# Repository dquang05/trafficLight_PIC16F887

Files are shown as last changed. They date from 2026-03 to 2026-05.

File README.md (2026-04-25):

# Traffic Light Controller with PIC16F887

<p align="center">
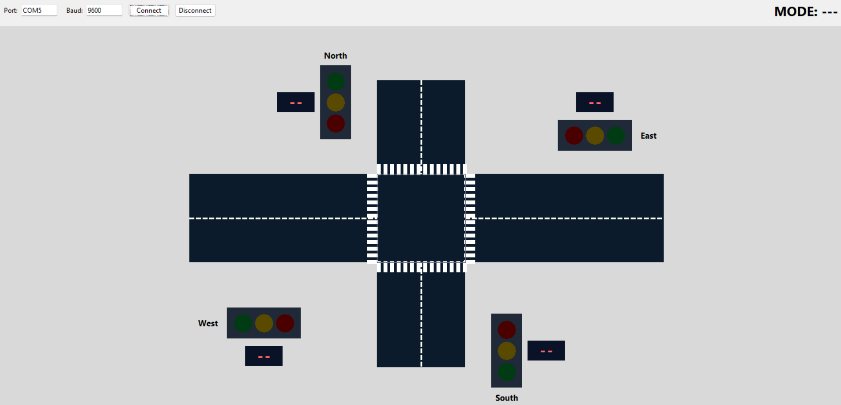
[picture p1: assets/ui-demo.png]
UI Demo
  
</p>

A embedded systems project that implements a 2-road traffic light controller on **PIC16F887**, with a **Python Tkinter desktop UI** for monitoring and control over UART. The project focuses on firmware development, peripheral integration, timer-based state control, and PC-side visualization.

## Features

- PIC16F887-based traffic light controller firmware
- 3 operating modes: **AUTO**, **MANUAL**, and **FLASHING**
- UART-based communication between the microcontroller and desktop UI
- Python Tkinter interface for live traffic light visualization
- I2C LCD for mode display on the hardware side
- Button control and serial command control support

## Operating Modes

### AUTO
Runs the normal traffic cycle automatically using timer-based state transitions. The UI displays countdown values for both roads.

### MANUAL
Allows the user to manually select which road gets the green light from the desktop UI.

### FLASHING
Puts the system into a caution mode where the yellow lights blink.

## How It Works

The PIC firmware handles the traffic light state machine, button input, UART command processing, and LCD updates. A timer interrupt is used for timekeeping, while the main loop updates the current mode and periodically sends system state data to the PC.

The desktop UI connects through a serial port, sends commands, and visualizes the current traffic light states in real time.

## Controls

Supported serial/UI commands:

- `A` → AUTO
- `N` → MANUAL
- `F` → FLASHING
- `M` → NEXT MODE
- `R1` → Road 1 Go
- `R2` → Road 2 Go

## How to Use

1. Build and flash the firmware to the PIC16F887.
2. Connect the board to the PC through UART.
3. Run the Python UI.
4. Select the correct COM port and baud rate, then press **Connect**.
5. Use the UI buttons to switch modes and control the intersection.

## Wiring Notes

- `RC3` → I2C SCL
- `RC4` → I2C SDA
- `RB0`, `RB1`, `RB2` → push buttons
- UART baud rate in the current setup: **9600**

## Fault notes
- This is a small project, i do not optimal it for fault tolerance, so there are some faults in the code, such as:
  - All the components must be connected or the hardware may not function correctly.
  - If the LCD is not properly initialized or connected, it will not run correctly until the MCU is reset.

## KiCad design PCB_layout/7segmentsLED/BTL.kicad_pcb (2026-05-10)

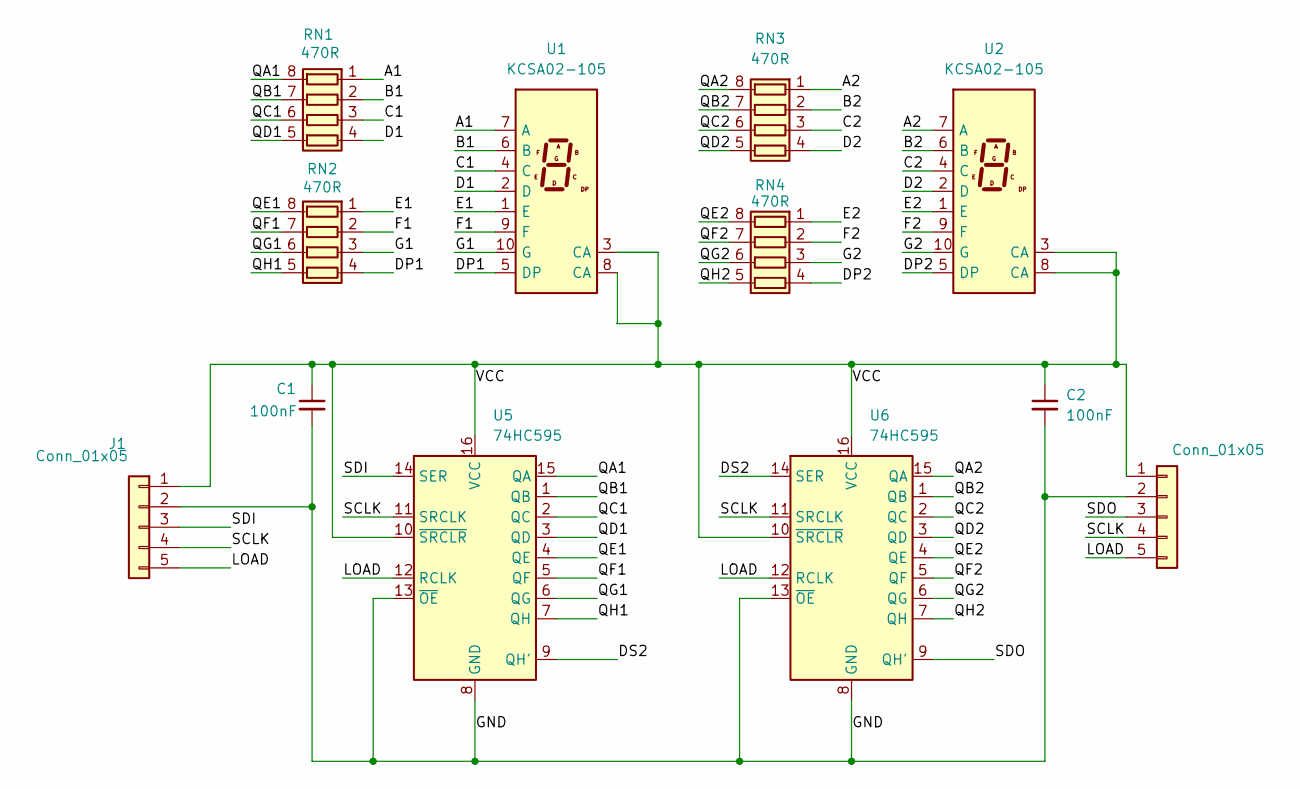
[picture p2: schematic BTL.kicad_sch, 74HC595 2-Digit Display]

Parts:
C1, C2: 100nF; C_0805_2012Metric
J1, J2: Conn_01x05; PinHeader_1x05_P2.54mm_Vertical
RN1, RN2, RN3, RN4: 470R; R_Array_Convex_4x0603
U1, U2: KCSA02-105; D1X8K
U5, U6: 74HC595; SOIC-16_3.9x9.9mm_P1.27mm

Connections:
/A1: RN1.1 (R1.1), U1.7 (A)
/A2: RN3.1 (R1.1), U2.7 (A)
/B1: RN1.2 (R2.1), U1.6 (B)
/B2: RN3.2 (R2.1), U2.6 (B)
/C1: RN1.3 (R3.1), U1.4 (C)
/C2: RN3.3 (R3.1), U2.4 (C)
/D1: RN1.4 (R4.1), U1.2 (D)
/D2: RN3.4 (R4.1), U2.2 (D)
/DP1: RN2.4 (R4.1), U1.5 (DP)
/DP2: RN4.4 (R4.1), U2.5 (DP)
/DS2: U5.9 (QH'), U6.14 (SER)
/E1: RN2.1 (R1.1), U1.1 (E)
/E2: RN4.1 (R1.1), U2.1 (E)
/F1: RN2.2 (R2.1), U1.9 (F)
/F2: RN4.2 (R2.1), U2.9 (F)
/G1: RN2.3 (R3.1), U1.10 (G)
/G2: RN4.3 (R3.1), U2.10 (G)
/GND: C1.2, C2.2, J1.2, J2.2, U5.8 (GND), U5.13 (~OE), U6.8 (GND), U6.13 (~OE)
/LOAD: J1.5, J2.5, U5.12 (RCLK), U6.12 (RCLK)
/QA1: RN1.8 (R1.2), U5.15 (QA)
/QA2: RN3.8 (R1.2), U6.15 (QA)
/QB1: RN1.7 (R2.2), U5.1 (QB)
/QB2: RN3.7 (R2.2), U6.1 (QB)
/QC1: RN1.6 (R3.2), U5.2 (QC)
/QC2: RN3.6 (R3.2), U6.2 (QC)
/QD1: RN1.5 (R4.2), U5.3 (QD)
/QD2: RN3.5 (R4.2), U6.3 (QD)
/QE1: RN2.8 (R1.2), U5.4 (QE)
/QE2: RN4.8 (R1.2), U6.4 (QE)
/QF1: RN2.7 (R2.2), U5.5 (QF)
/QF2: RN4.7 (R2.2), U6.5 (QF)
/QG1: RN2.6 (R3.2), U5.6 (QG)
/QG2: RN4.6 (R3.2), U6.6 (QG)
/QH1: RN2.5 (R4.2), U5.7 (QH)
/QH2: RN4.5 (R4.2), U6.7 (QH)
/SCLK: J1.4, J2.4, U5.11 (SRCLK), U6.11 (SRCLK)
/SDI: J1.3, U5.14 (SER)
/SDO: J2.3, U6.9 (QH')
/VCC: C1.1, C2.1, J1.1, J2.1, U1.3 (CA), U1.8 (CA), U2.3 (CA), U2.8 (CA), U5.10 (~SRCLR), U5.16 (VCC), U6.10 (~SRCLR), U6.16 (VCC)

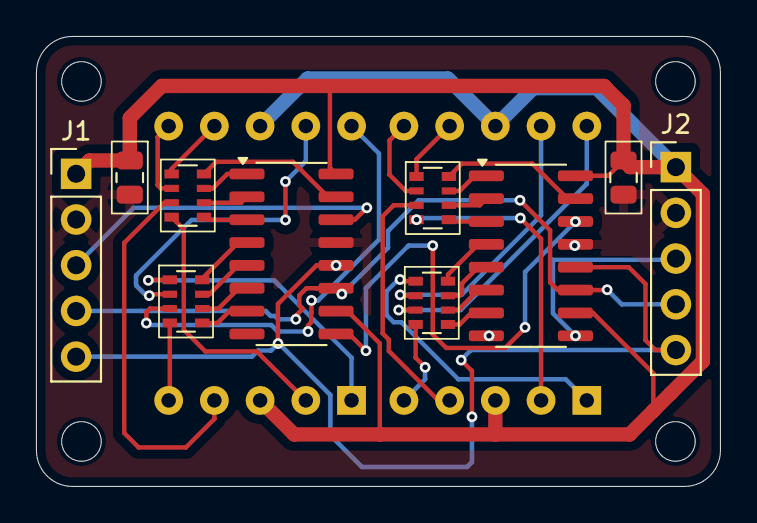
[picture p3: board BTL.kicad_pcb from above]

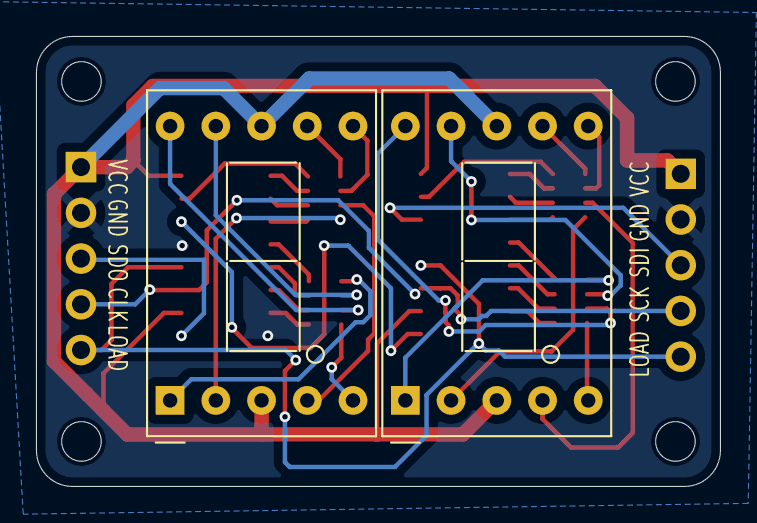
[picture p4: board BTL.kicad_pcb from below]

Board: 2 copper layers, 38.0 x 25.0 mm, 12 parts (2 on the bottom side), 39 nets.

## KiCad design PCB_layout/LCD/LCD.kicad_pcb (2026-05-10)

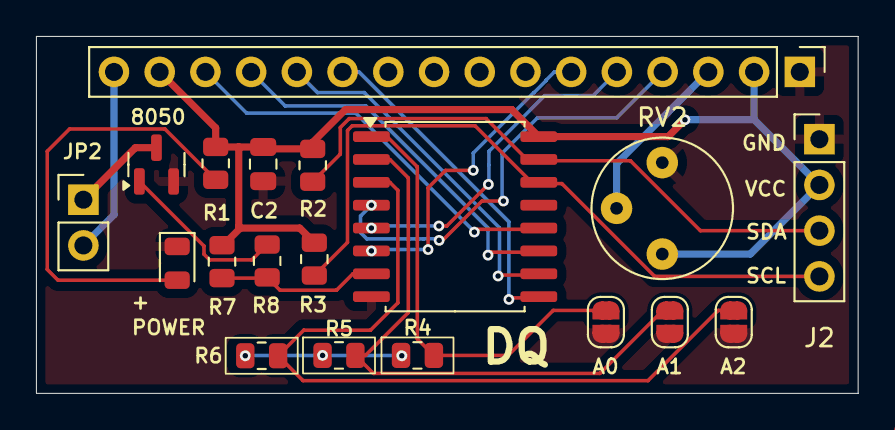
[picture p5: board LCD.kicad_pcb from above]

Board: 2 copper layers, 45.6 x 19.8 mm, 19 parts (0 on the bottom side), 20 nets.

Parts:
8050: SS8050; SOT-23
A0, A1, A2: SolderJumper_2_Open; SolderJumper-2_P1.3mm_Open_RoundedPad1.0x1.5mm
C2: C; C_0805_2012Metric
J1: Conn_01x16; PinHeader_1x16_P2.54mm_Vertical
J2: Conn_01x04; PinHeader_1x04_P2.54mm_Vertical
JP2: Jumper_2_Bridged; PinHeader_1x02_P2.54mm_Vertical
POWER: LED; LED_0805_2012Metric
R1: 1k; R_0805_2012Metric
R1#2, R2, R2#2, R3, R3#2, R7, R8: 4k7; R_0805_2012Metric
RV2: 10k; Potentiometer_Bourns_3339P_Vertical_HandSoldering
U1: PCF8574T; SOIC-16W_7.5x10.3mm_P1.27mm

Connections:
BL: R7.2, R8.2, U1.7 (P3)
D4: J1.11, U1.9 (P4)
D5: J1.12, U1.10 (P5)
D6: J1.13, U1.11 (P6)
D7: J1.14, U1.12 (P7)
EN: J1.6, U1.6 (P2)
GND: 8050.2 (E), A0.2 (B), A1.2 (B), A2.2 (B), C2.2, J1.1, J2.1, POWER.1 (K), RV2.3, U1.8 (GND)
K: J1.16, JP2.2 (B)
unnamed: POWER.2 (A), R1.2
unnamed: 8050.3 (C), JP2.1 (A)
unnamed: A2.1 (A), R1#2.2, U1.3 (A2)
unnamed: A1.1 (A), R2.2, U1.2 (A1)
unnamed: A0.1 (A), R3.2, U1.1 (A0)
unnamed: 8050.1 (B), R8.1
RS: J1.4, U1.4 (P0)
RW: J1.5, U1.5 (P1)
SCL: J2.4, R3#2.2, U1.14 (SCL)
SDA: J2.3, R2#2.2, U1.15 (SDA)
V0: J1.3, RV2.2
VDD: C2.1, J1.2, J1.15, J2.2, R1.1, R1#2.1, R2.1, R2#2.1, R3.1, R3#2.1, R7.1, RV2.1, U1.16 (VDD)

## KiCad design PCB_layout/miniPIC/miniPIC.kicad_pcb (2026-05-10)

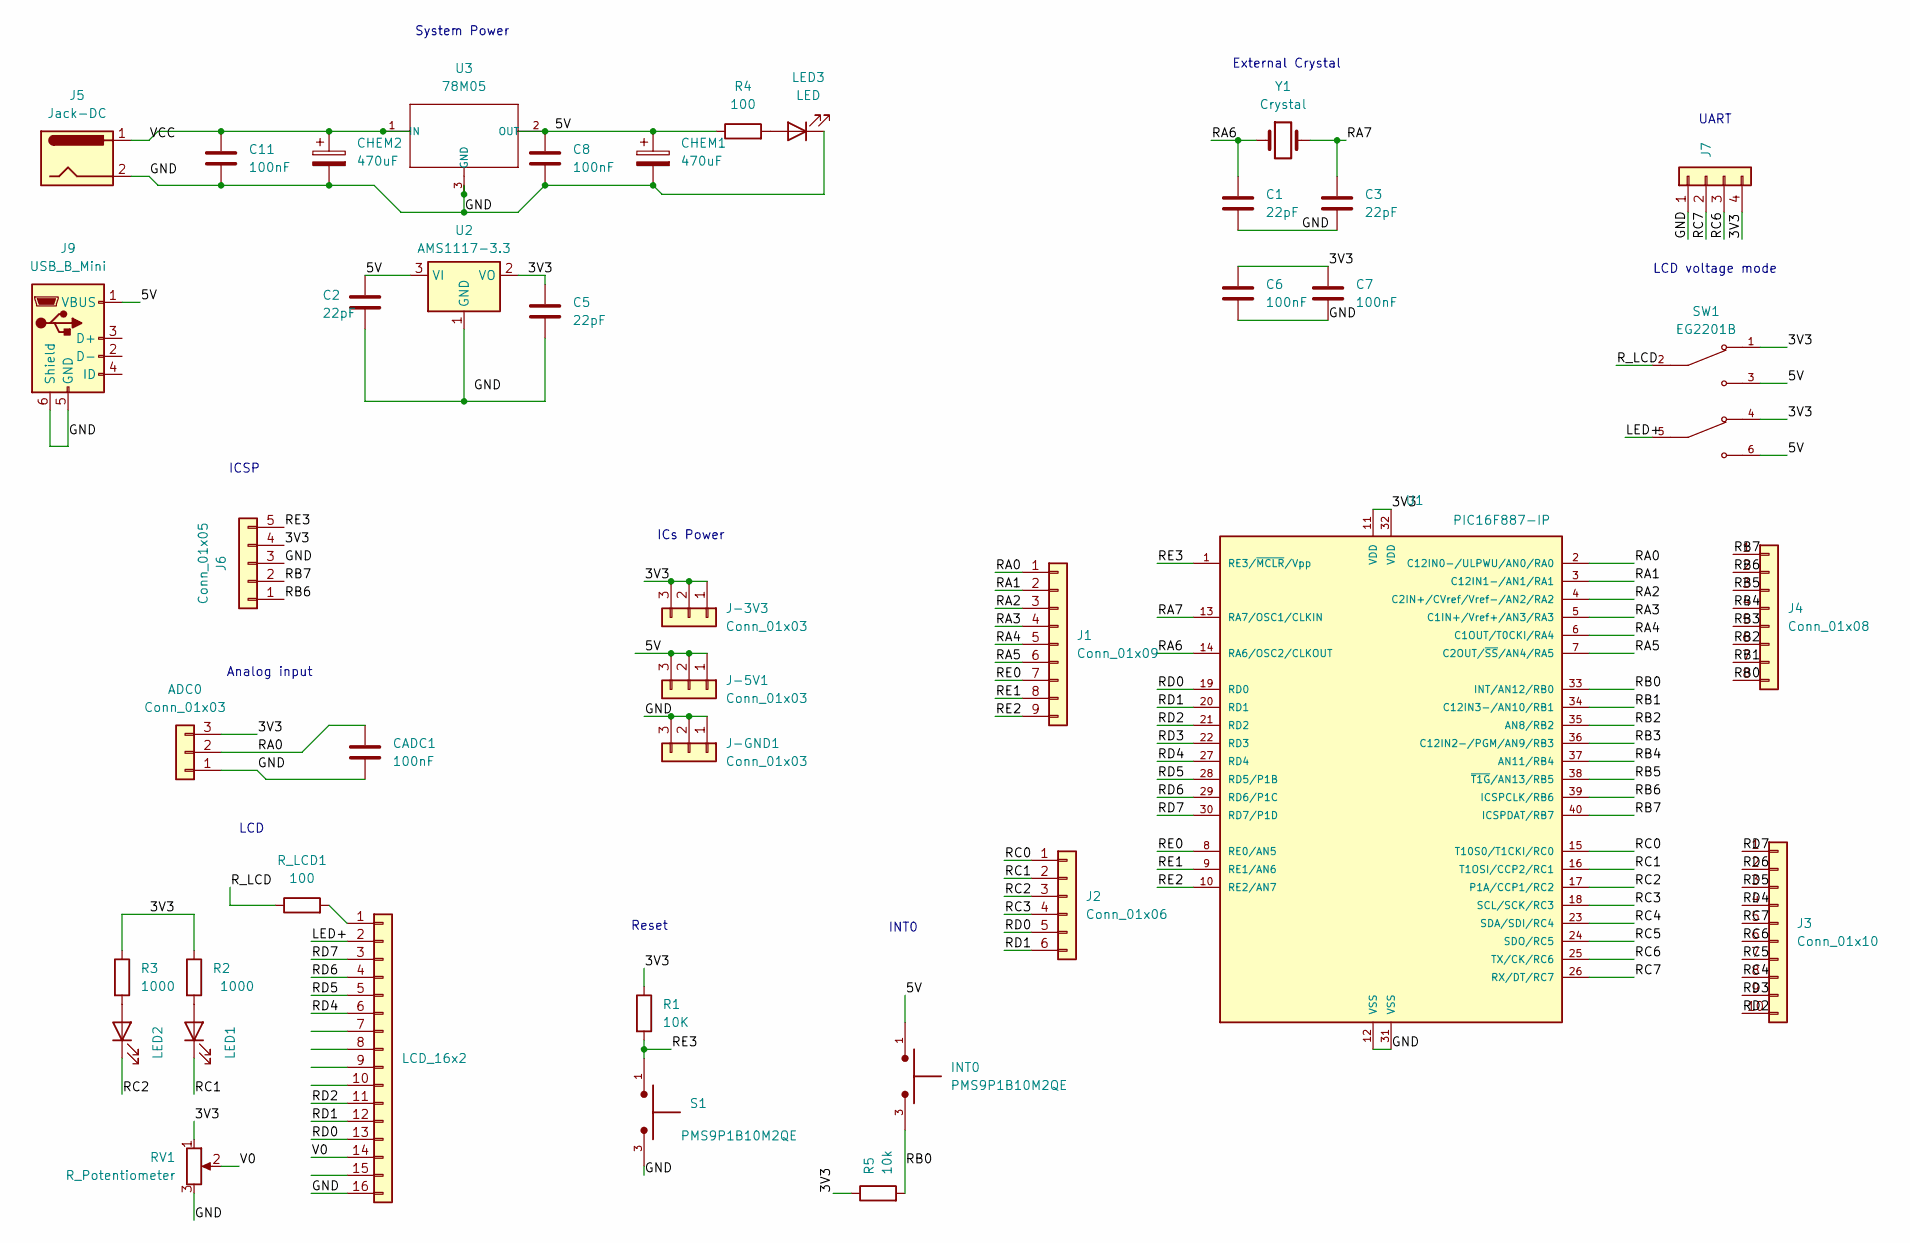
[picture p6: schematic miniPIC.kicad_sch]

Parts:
ADC0: Conn_01x03; PinHeader_1x03_P2.54mm_Vertical
C1, C2, C3, C5: 22pF; CP_EIA-1608-08_AVX-J
C6, C7, C8, C11: 100nF; CP_EIA-1608-08_AVX-J
CADC1: 100nF; CP_EIA-1608-08_AVX-J
CHEM1, CHEM2: 470uF; CP_Radial_D7.5mm_P2.50mm
INT0: PMS9P1B10M2QE; SW_PMS9P1B10M2QE; PARTREV A1
J1: Conn_01x09; PinHeader_1x09_P2.54mm_Vertical
J2: Conn_01x06; PinHeader_1x06_P2.54mm_Vertical
J3: Conn_01x10; PinHeader_1x10_P2.54mm_Vertical
J4: Conn_01x08; PinHeader_1x08_P2.54mm_Vertical
J5: Jack-DC; BarrelJack_Horizontal
J6: Conn_01x05; PinHeader_1x05_P2.54mm_Vertical
J7: Conn_01x04; PinSocket_1x04_P2.54mm_Vertical
J9: USB_B_Mini; USB_Mini-B_Lumberg_2486_01_Horizontal
J-3V3, J-5V1: Conn_01x03; PinHeader_1x03_P2.54mm_Vertical
J-GND1: Conn_01x03; PinHeader_1x03_P2.54mm_Vertical
LCD_16x2: Conn_01x16; PinSocket_1x16_P2.54mm_Vertical
LED1, LED2: LED; LED_0603_1608Metric_Pad1.05x0.95mm_HandSolder
LED3: LED; LED_1206_3216Metric_Pad1.42x1.75mm_HandSolder
R1: 10K; R_0805_2012Metric_Pad1.20x1.40mm_HandSolder
R2, R3: 1000; R_0805_2012Metric_Pad1.20x1.40mm_HandSolder
R4: 100; R_0805_2012Metric_Pad1.20x1.40mm_HandSolder
R5: 10k; R_0805_2012Metric_Pad1.20x1.40mm_HandSolder
RV1: R_Potentiometer; Potentiometer_Bourns_3266W_Vertical
R_LCD1: 100; R_0805_2012Metric_Pad1.20x1.40mm_HandSolder
S1: PMS9P1B10M2QE; SW_PMS9P1B10M2QE; PARTREV A1
SW1: EG2201B; SW_EG2201B; PARTREV C
U1: PIC16F887-IP; DIP1543W47P254L5175H635Q40
U2: AMS1117-3.3; SOT-223-3_TabPin2
U3: 78M05; TO-252-2
Y1: Crystal; Crystal_HC49-4H_Vertical

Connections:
/3V3: ADC0.3, C5.1, C6.1, C7.1, J6.4, J7.4, J-3V3.1, J-3V3.2, J-3V3.3, R1.1, R2.1, R3.1, R5.1, RV1.1, SW1.1, SW1.4, U1.11 (VDD), U1.32 (VDD), U2.2 (VO)
/5V: C2.1, C8.1, CHEM1.1, INT0.1, J9.1 (VBUS), J-5V1.1, J-5V1.2, J-5V1.3, R4.1, SW1.3, SW1.6, U2.3 (VI), U3.2 (OUT)
/LED+: LCD_16x2.2, SW1.5
/RA0: ADC0.2, CADC1.1, J1.1, U1.2 (C12IN0-/ULPWU/AN0/RA0)
/RA1: J1.2, U1.3 (C12IN1-/AN1/RA1)
/RA2: J1.3, U1.4 (C2IN+/CVref/Vref-/AN2/RA2)
/RA3: J1.4, U1.5 (C1IN+/Vref+/AN3/RA3)
/RA4: J1.5, U1.6 (C1OUT/T0CKI/RA4)
/RA5: J1.6, U1.7 (C2OUT/~SS/AN4/RA5)
/RA6: C1.1, U1.14 (RA6/OSC2/CLKOUT), Y1.1
/RA7: C3.1, U1.13 (RA7/OSC1/CLKIN), Y1.2
/RB0: INT0.3, J4.8, R5.2, U1.33 (INT/AN12/RB0)
/RB1: J4.7, U1.34 (C12IN3-/AN10/RB1)
/RB2: J4.6, U1.35 (AN8/RB2)
/RB3: J4.5, U1.36 (C12IN2-/PGM/AN9/RB3)
/RB4: J4.4, U1.37 (AN11/RB4)
/RB5: J4.3, U1.38 (~T1G/AN13/RB5)
/RB6: J4.2, J6.1, U1.39 (ICSPCLK/RB6)
/RB7: J4.1, J6.2, U1.40 (ICSPDAT/RB7)
/RC0: J2.1, U1.15 (T10S0/T1CKI/RC0)
/RC1: J2.2, LED1.1 (K), U1.16 (T1OSI/CCP2/RC1)
/RC2: J2.3, LED2.1 (K), U1.17 (P1A/CCP1/RC2)
/RC3: J2.4, U1.18 (SCL/SCK/RC3)
/RC4: J3.8, U1.23 (SDA/SDI/RC4)
/RC5: J3.7, U1.24 (SDO/RC5)
/RC6: J3.6, J7.3, U1.25 (TX/CK/RC6)
/RC7: J3.5, J7.2, U1.26 (RX/DT/RC7)
/RD0: J2.5, LCD_16x2.13, U1.19 (RD0)
/RD1: J2.6, LCD_16x2.12, U1.20 (RD1)
/RD2: J3.10, LCD_16x2.11, U1.21 (RD2)
/RD3: J3.9, U1.22 (RD3)
/RD4: J3.4, LCD_16x2.6, U1.27 (RD4)
/RD5: J3.3, LCD_16x2.5, U1.28 (RD5/P1B)
/RD6: J3.2, LCD_16x2.4, U1.29 (RD6/P1C)
/RD7: J3.1, LCD_16x2.3, U1.30 (RD7/P1D)
/RE0: J1.7, U1.8 (RE0/AN5)
/RE1: J1.8, U1.9 (RE1/AN6)
/RE2: J1.9, U1.10 (RE2/AN7)
/RE3: J6.5, R1.2, S1.1, U1.1 (RE3/~MCLR/Vpp)
/R_LCD: R_LCD1.1, SW1.2
/V0: LCD_16x2.14, RV1.2
/VCC: C11.1, CHEM2.1, J5.1, U3.1 (IN)
unnamed: LCD_16x2.1, R_LCD1.2
unnamed: LED1.2 (A), R2.2
unnamed: LED2.2 (A), R3.2
unnamed: LED3.2 (A), R4.2

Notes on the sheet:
External Crystal
LCD
Reset
UART
System Power
INT0
LCD voltage mode
ICSP
ICs Power
Analog input

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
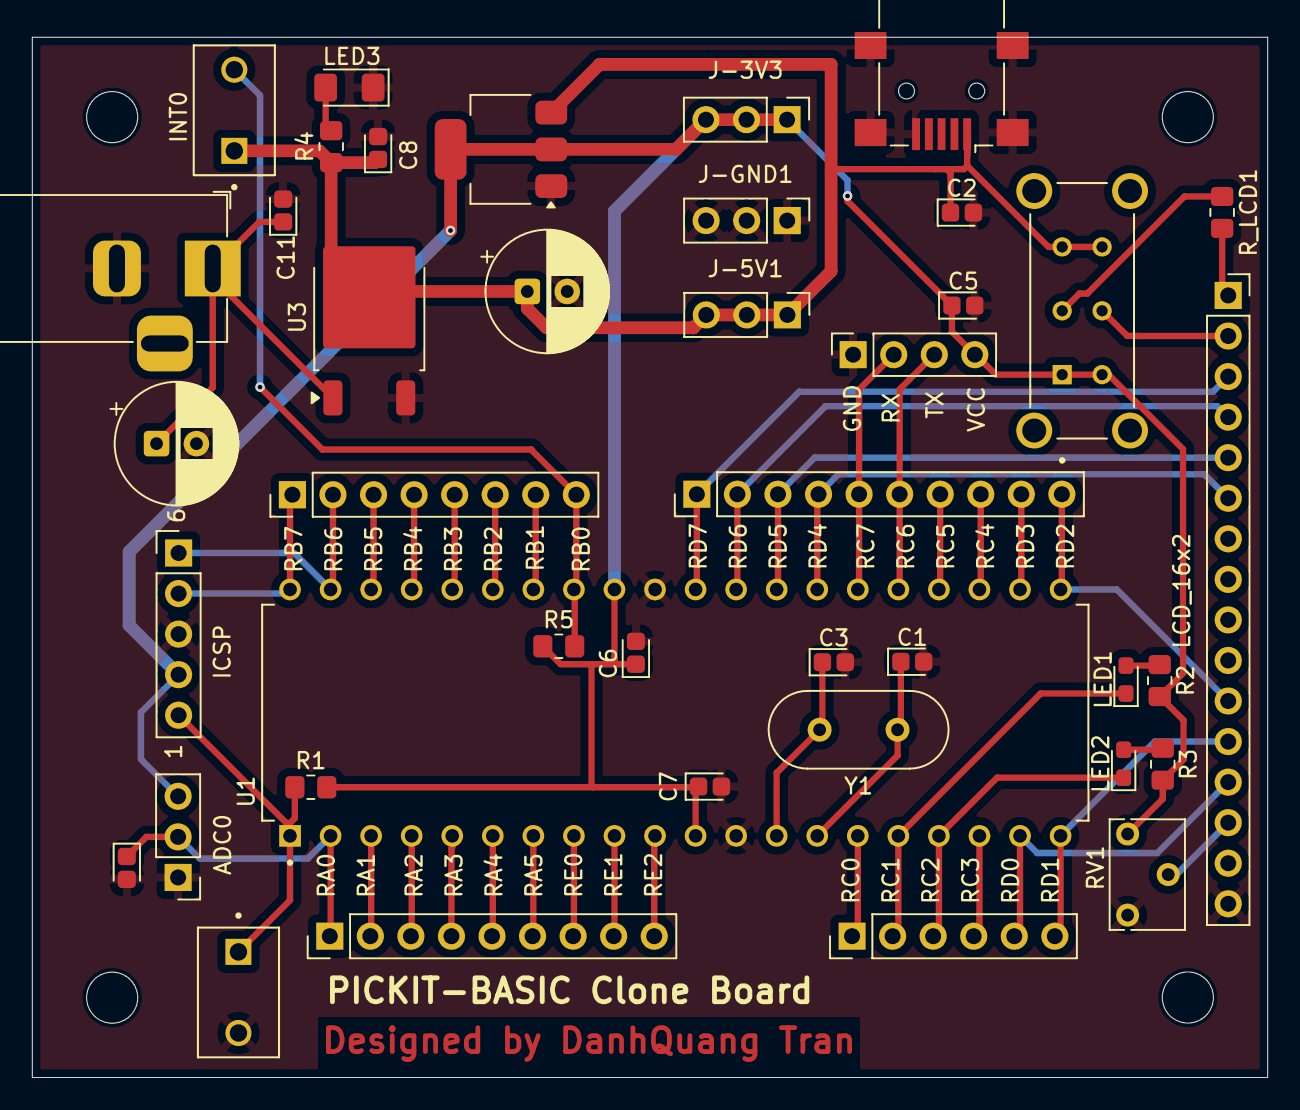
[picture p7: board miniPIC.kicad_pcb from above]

Board: 2 copper layers, 77.4 x 65.2 mm, 41 parts (0 on the bottom side), 47 nets.

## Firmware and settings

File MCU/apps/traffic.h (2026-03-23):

#ifndef TRAFFIC_H
#define TRAFFIC_H

#include <stdint.h>
#include <xc.h> 

// Các thông số thời gian
#define GREEN1_TIME   15
#define GREEN2_TIME   15
#define YELLOW_TIME  3

// Định nghĩa chân đèn giao thông
#define GREEN1   RA0  
#define YELLOW1  RA1  
#define RED1     RA2         
#define GREEN2   RA3  
#define YELLOW2  RA4    
#define RED2     RA5     

// Các biến toàn cục
extern volatile uint16_t timer_counter;
extern volatile uint8_t system_state;
extern volatile uint8_t exitsign;
extern volatile uint8_t mode;
extern volatile uint8_t countdown_NS; 
extern volatile uint8_t countdown_EW; 
extern volatile uint8_t road1_flag;
extern volatile uint8_t road2_flag;

// Các hàm điều khiển đèn
void Auto_Mode_Timer(void);
void Midnight_Mode_Timer(void);
void Manual_Mode(void);
void Opposite_State(void);
void Display_Countdown(uint8_t countdown_EW, uint8_t countdown_NS);
void ShiftOut_1Byte(uint8_t data);
void Clear_Display(void);

#endif

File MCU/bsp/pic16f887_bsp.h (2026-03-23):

#include <xc.h> // include processor files - each processor file is guarded.  

// CONFIG1
#pragma config FOSC = INTRC_NOCLKOUT        // Oscillator Selection bits (RC oscillator: CLKOUT function on RA6/OSC2/CLKOUT pin, RC on RA7/OSC1/CLKIN)
#pragma config WDTE = OFF       // Watchdog Timer Enable bit (WDT disabled and can be enabled by SWDTEN bit of the WDTCON register)

#pragma config CP = OFF         // Code Protection bit (Program memory code protection is disabled)
#pragma config CPD = OFF        // Data Code Protection bit (Data memory code protection is disabled)
#pragma config BOREN = ON       // Brown Out Reset Selection bits (BOR enabled)
#pragma config IESO = OFF       // Internal External Switchover bit (Internal/External Switchover mode is disabled)
#pragma config FCMEN = OFF      // Fail-Safe Clock Monitor Enabled bit (Fail-Safe Clock Monitor is disabled)
#pragma config LVP = OFF        // Low Voltage Programming Enable bit (RB3 pin has digital I/O, HV on MCLR must be used for programming)

// CONFIG2
#pragma config BOR4V = BOR40V   // Brown-out Reset Selection bit (Brown-out Reset set to 4.0V)
#pragma config WRT = OFF        // Flash Program Memory Self Write Enable bits (Write protection off)

// #pragma config statements should precede project file includes.
// Use project enums instead of #define for ON and OFF.

#define _XTAL_FREQ 4000000 // Set the clock frequency to 4MHz

#pragma config PWRTE = ON       // Power-up Timer Enable bit (PWRT enabled)
#pragma config MCLRE = ON       // RE3/MCLR pin function select bit (RE3/MCLR pin function is digital input, MCLR internally tied to VDD)

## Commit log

2026-04-19 fix: ignore unecessary files
    [miniPIC.kicad_pcb, miniPIC.kicad_sch]
2026-04-23 add: two physical button to change mode on lane
2026-04-23 fix: 2 button conditions
    [main.c]
2026-04-25 fix: ignore cmake generated files
    [main.c]
2026-05-10 add: PCB_layout
    [BTL.kicad_pcb, BTL.kicad_sch, LCD.kicad_pcb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]
